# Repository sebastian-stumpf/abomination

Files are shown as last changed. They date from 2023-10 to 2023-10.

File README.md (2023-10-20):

# abomination

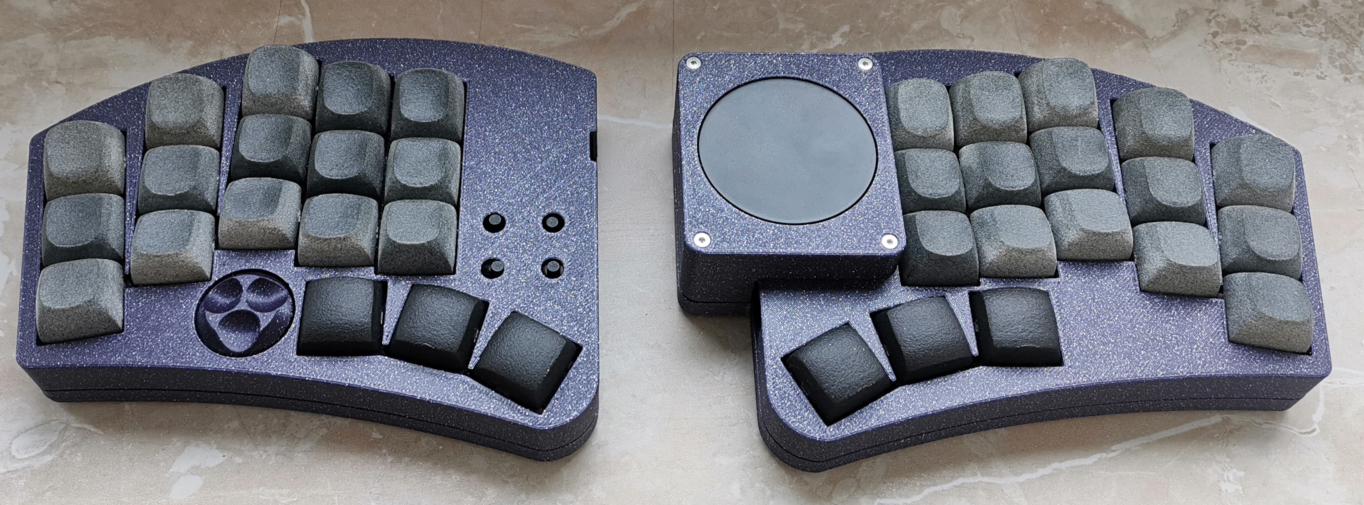
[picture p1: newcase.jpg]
abomination


## Attention

I'm a hobbyist/amateur at best. So there may be things that aren't optimized. That being said I've had the files
in the `gerbers/` directory manufactured at JLC with 1.6mm thickness and they work just fine with my fork of the qmk repository
directory. So if you decide to use this, then please be advised that I'm not providing any sort of liability and you should
exercise some caution.

## Trackpad

The trackpad relies on the following adapter https://github.com/keyboard-magpie/minimal-fpc-i2c-pcb/ which can cheapily be PCBA'ed.
There reasons for using this adapter are that I hate soldering those tiny clamshell connectors and I can easily hot swap the
trackpad with an OLED display.

## Case

There are two plate versions for the case. The default version is very thin and wobbly and the switches aren't pressed in easily.
There's also a 'thick' version of the plates that sits on the pcb rock solid and the switches pop in with ease. I'd heavily recommend
the thick version. Just be aware that it will consume about 4 times the material as the thin plate.

## BOM

| Quantity | Item | Comment |
| ---  | --- | --- |
| 2 | Helios or Liatris Controller | |
| 2 | IC-Sockets for MCU | Optional but recommended |
| 2 | TRRS Sockets | |
| 40 | 1N4148 SOD123 diodes | |
| 2 | SKHLLBA010 buttons | |
| 36 | MX Hotswap Sockets | |
| 1 | EC12 Encoders | |
| 4 | 6mm tactile switches | Longer caps work best |
| 36 | MX Switches + Keycaps | |
| 1 | Cirque 40mm curved trackpad | Desolder R1 for i2c |
| 1 | i2c adapter PCB for trackpad | see above |
| 1 | fpc cable for adapter | |
| 1 | 4 pin dip socket and header | for the adapter |
| a lot | M2 Screws (flat & countersunk) | |
| also a lot | M2 heat inserts | |
| 12 | round bumpons with 3,1mm dia | |

## Firmware

See [my fork](https://github.com/sebastian-stumpf/qmk_firmware/tree/sepp/keyboards/abomination) of the qmk repository. Nothing special here.
You can just copy the code over to your own repository and adjust the keymap.

## Feedback

I'm always happy to hear your opinions about this and if you decide to build this board then please do send me a picture of it.

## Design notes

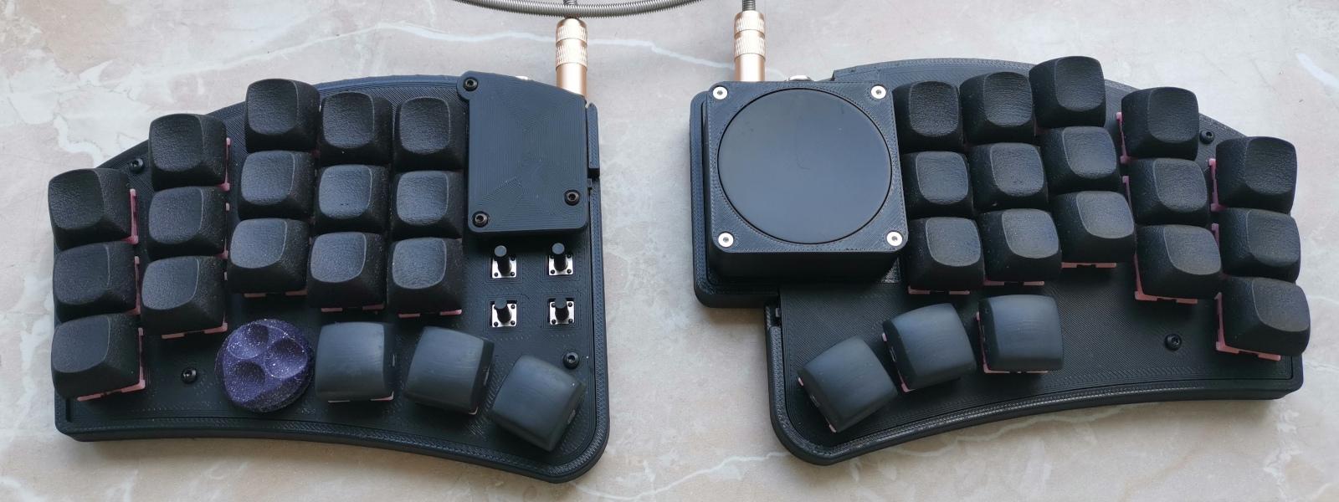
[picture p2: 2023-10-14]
abomination.jpg

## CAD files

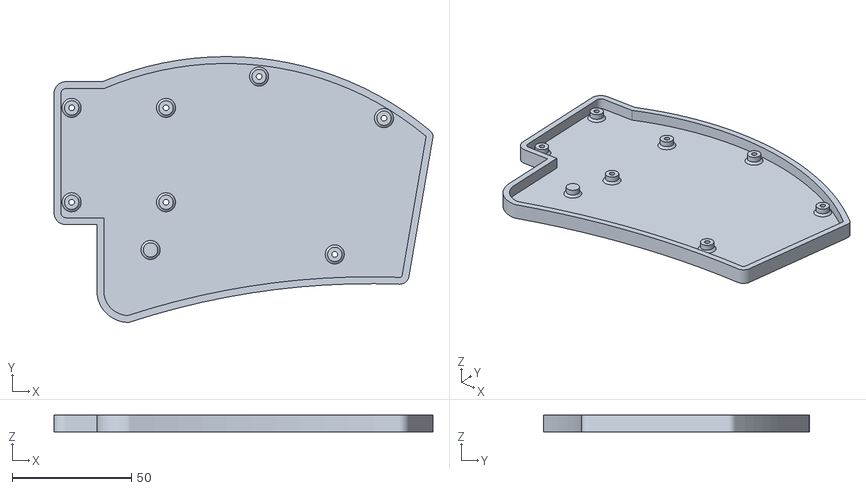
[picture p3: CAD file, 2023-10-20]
mechanical/case-new-right-bottom.stl
159.0 x 111.5 x 7.00

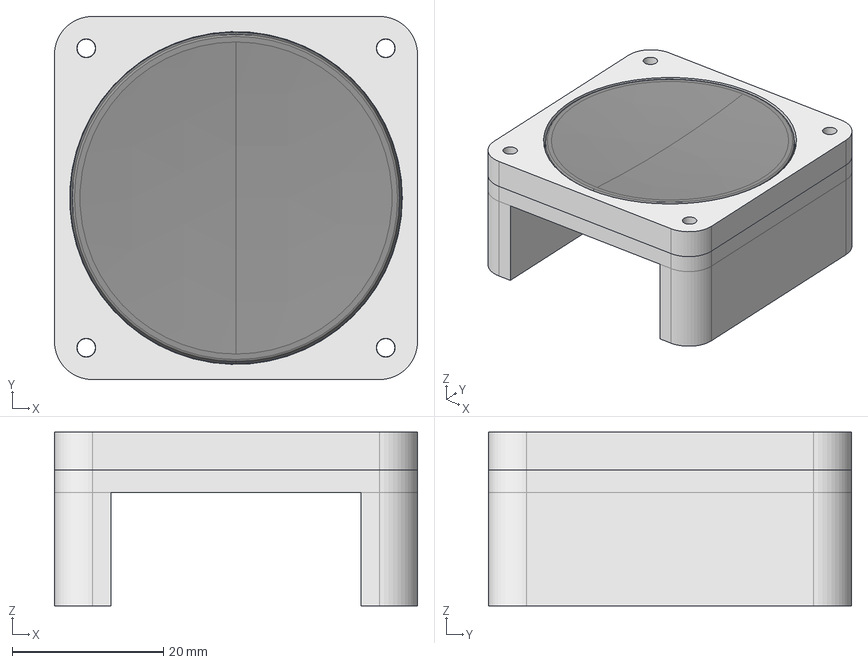
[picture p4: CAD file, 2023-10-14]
models/trackpad-holder.step
48.0 x 48.0 x 23.0 mm
trackpad
top
bottom

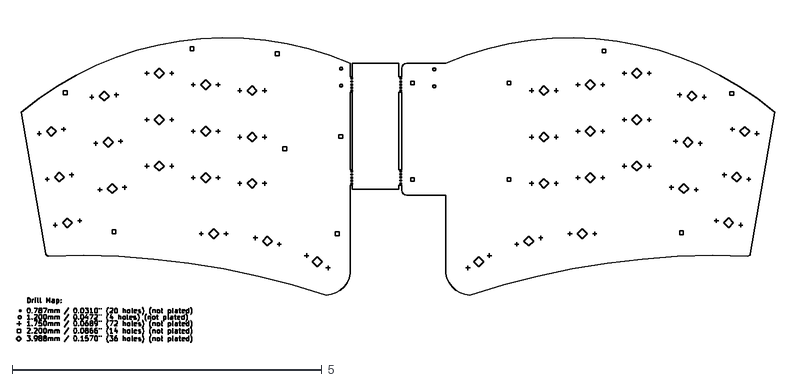
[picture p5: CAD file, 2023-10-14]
pcb/gerbers/abomination-NPTH-drl_map.dxf
12.2 x 5.27

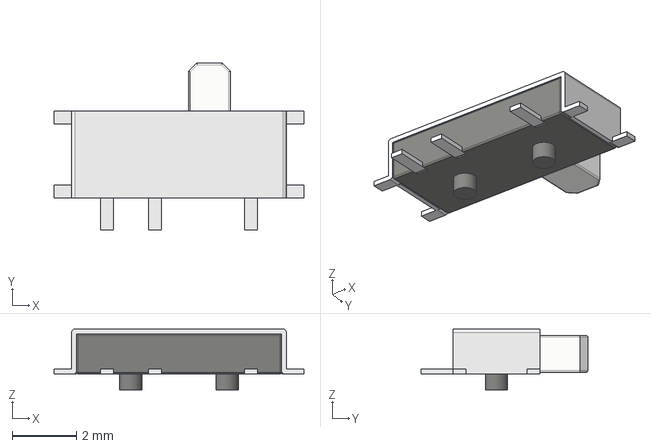
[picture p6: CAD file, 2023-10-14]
pcb/sepp/models/MSK12C02.step
7.80 x 5.20 x 1.90 mm

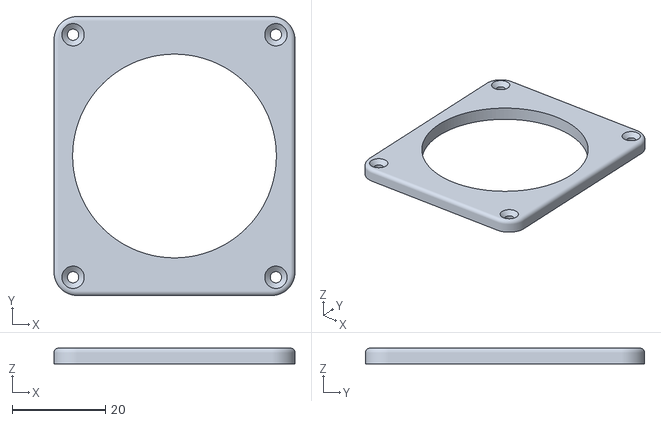
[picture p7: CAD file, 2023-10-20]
mechanical/case-new-right-cover.stl
51.8 x 60.0 x 3.41

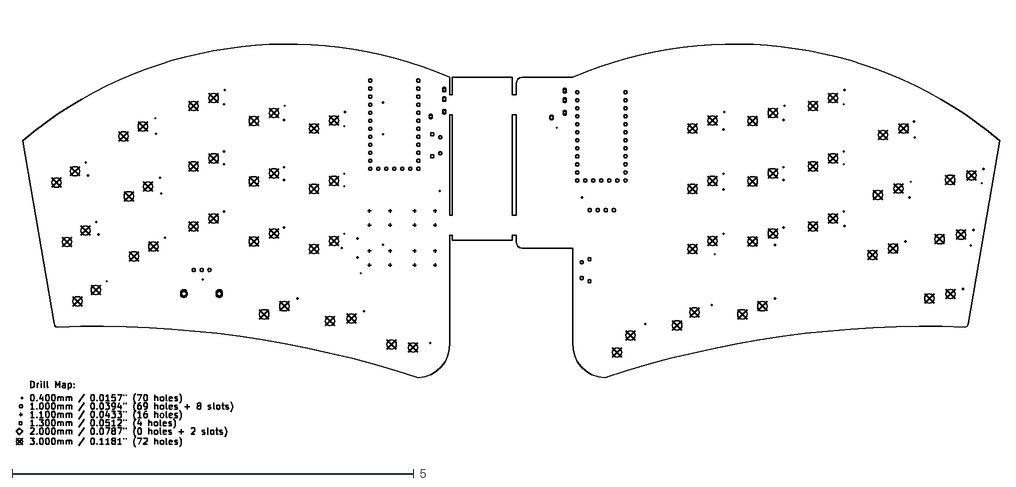
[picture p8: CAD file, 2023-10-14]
pcb/gerbers/abomination-PTH-drl_map.dxf
12.2 x 5.36

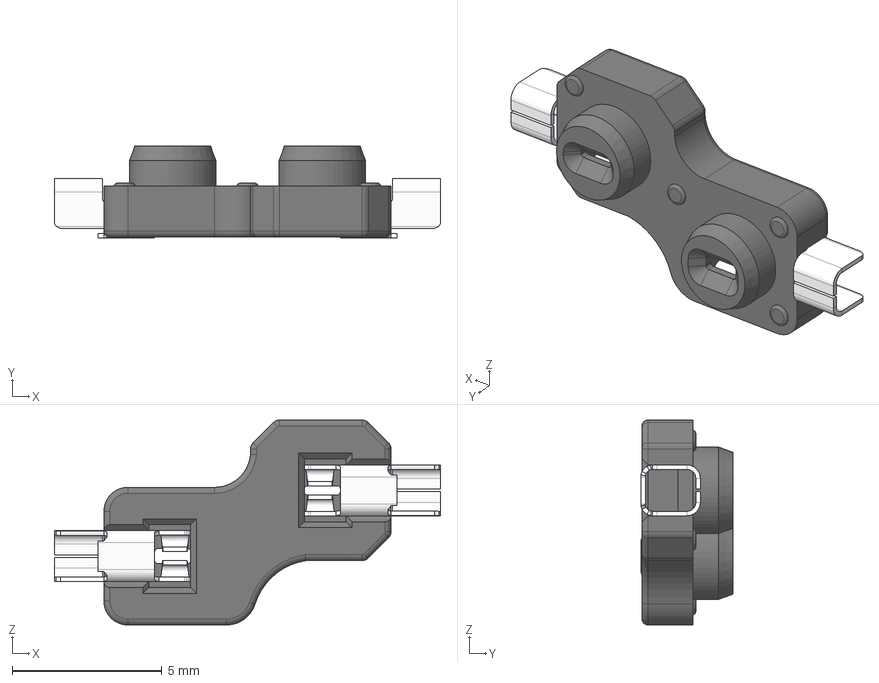
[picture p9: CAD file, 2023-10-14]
pcb/sepp/models/HS_Kailh_Choc.step
12.9 x 3.09 x 6.85 mm
pin x 2
socket

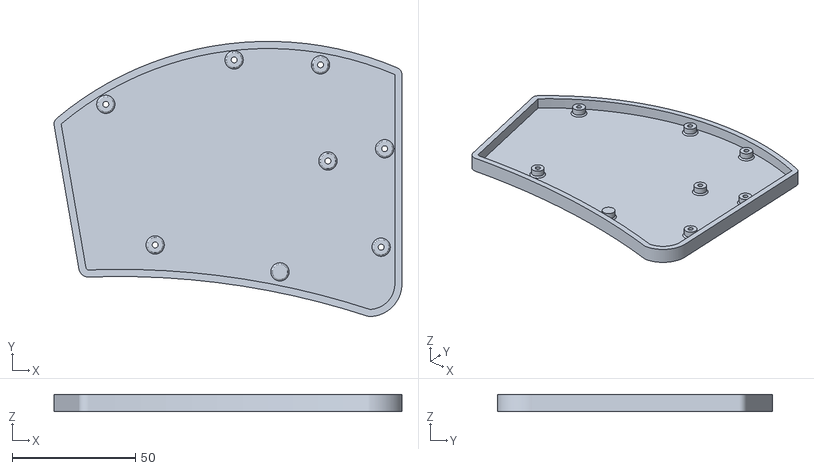
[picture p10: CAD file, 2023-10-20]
mechanical/case-new-left-bottom.stl
141.0 x 111.5 x 7.00

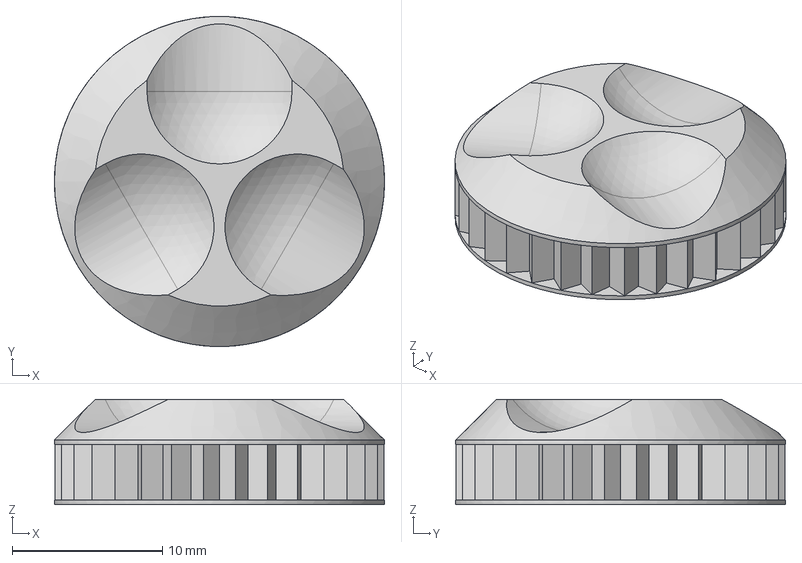
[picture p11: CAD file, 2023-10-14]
pcb/sepp/models/GEIST_EC12knob_v02_06.step
22.0 x 22.0 x 7.00 mm

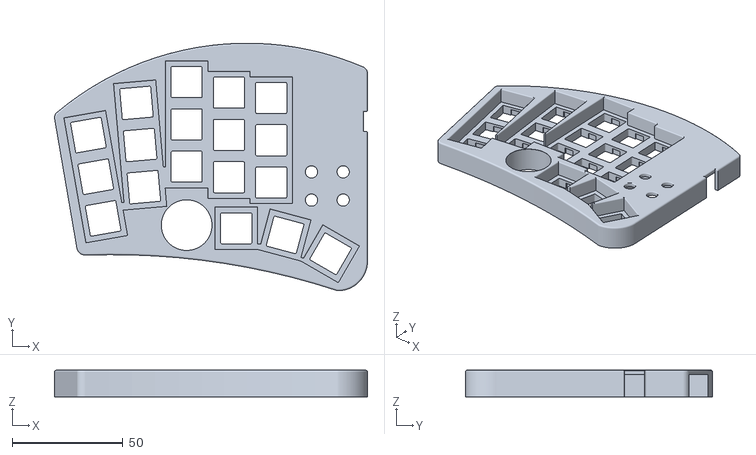
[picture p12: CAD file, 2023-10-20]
mechanical/case-new-left-top.stl
141.0 x 111.5 x 12.0

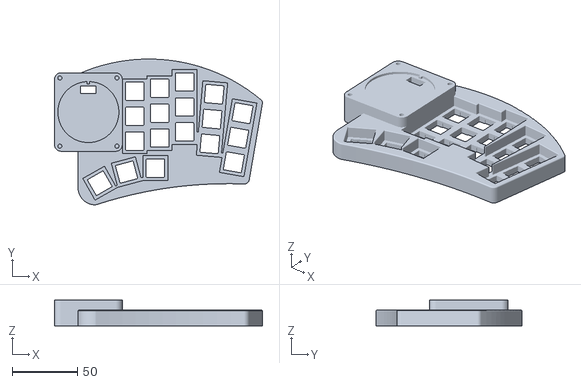
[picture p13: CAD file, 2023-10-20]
mechanical/case-new-right-top.stl
159.0 x 111.5 x 19.5

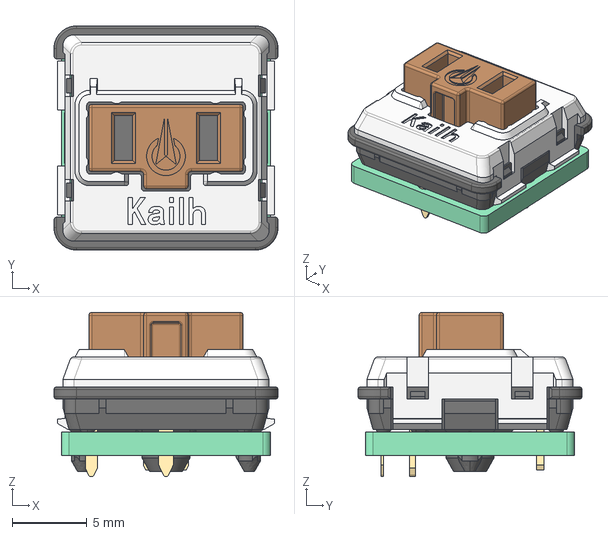
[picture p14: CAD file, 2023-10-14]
pcb/sepp/models/pg1350.step
15.0 x 15.0 x 11.0 mm

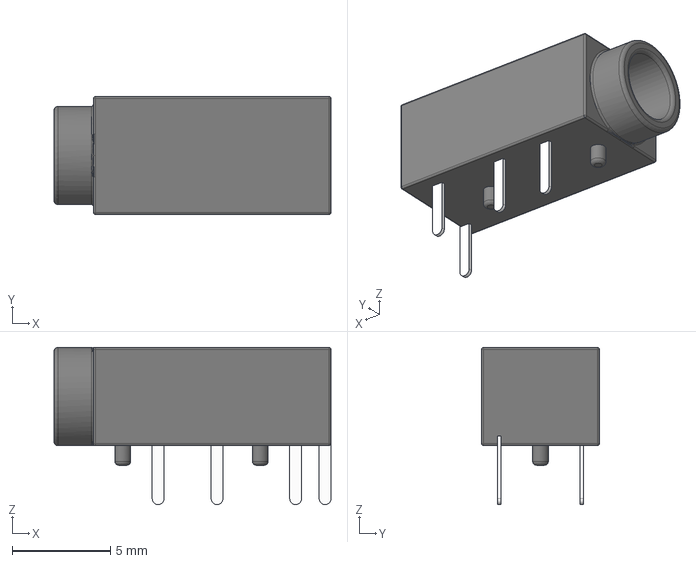
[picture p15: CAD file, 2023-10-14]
pcb/sepp/models/CON_MJ-4PP-9.step
14.1 x 6.00 x 8.00 mm

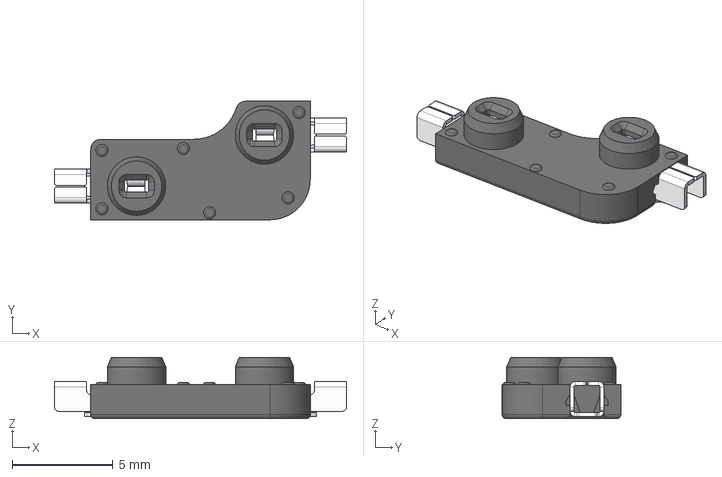
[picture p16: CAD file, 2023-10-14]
pcb/sepp/models/HS_Kailh_MX.step
14.5 x 5.89 x 3.05 mm
Contact x 2

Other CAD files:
pcb/sepp/models/SW_MSK12C02.step
pcb/sepp/models/xiao_rp2040.step
pcb/sepp/models/Liatris.step
pcb/sepp/models/MBK-1u.step
mechanical/old/case-left-bottom.stl
mechanical/old/case-left-cover.stl
mechanical/old/case-left-plate.stl
mechanical/old/case-left-thick-plate.stl
mechanical/old/case-right-bottom.stl
mechanical/old/case-right-plate.stl
mechanical/old/case-right-thick-plate.stl
mechanical/old/case-right-trackpad-plate.stl
mechanical/old/case-right-trackpad-top.stl
pcb/sepp/models/EC11-THT-15F-black.step
pcb/sepp/models/EC12E-085.step
pcb/sepp/models/LED_SK6812MINI-E.step
pcb/sepp/models/SKRTLAE010.step
pcb/sepp/models/SW_PUSH_6mm.step
pcb/sepp/models/SW_SKHLLC.step
pcb/sepp/models/abomination-trackpad-holder.step
pcb/sepp/models/cherry mx.STEP
pcb/sepp/models/fpc-connector-breakout.step
pcb/sepp/models/mx_kecap.step
pcb/sepp/models/pg1350-mbk.step

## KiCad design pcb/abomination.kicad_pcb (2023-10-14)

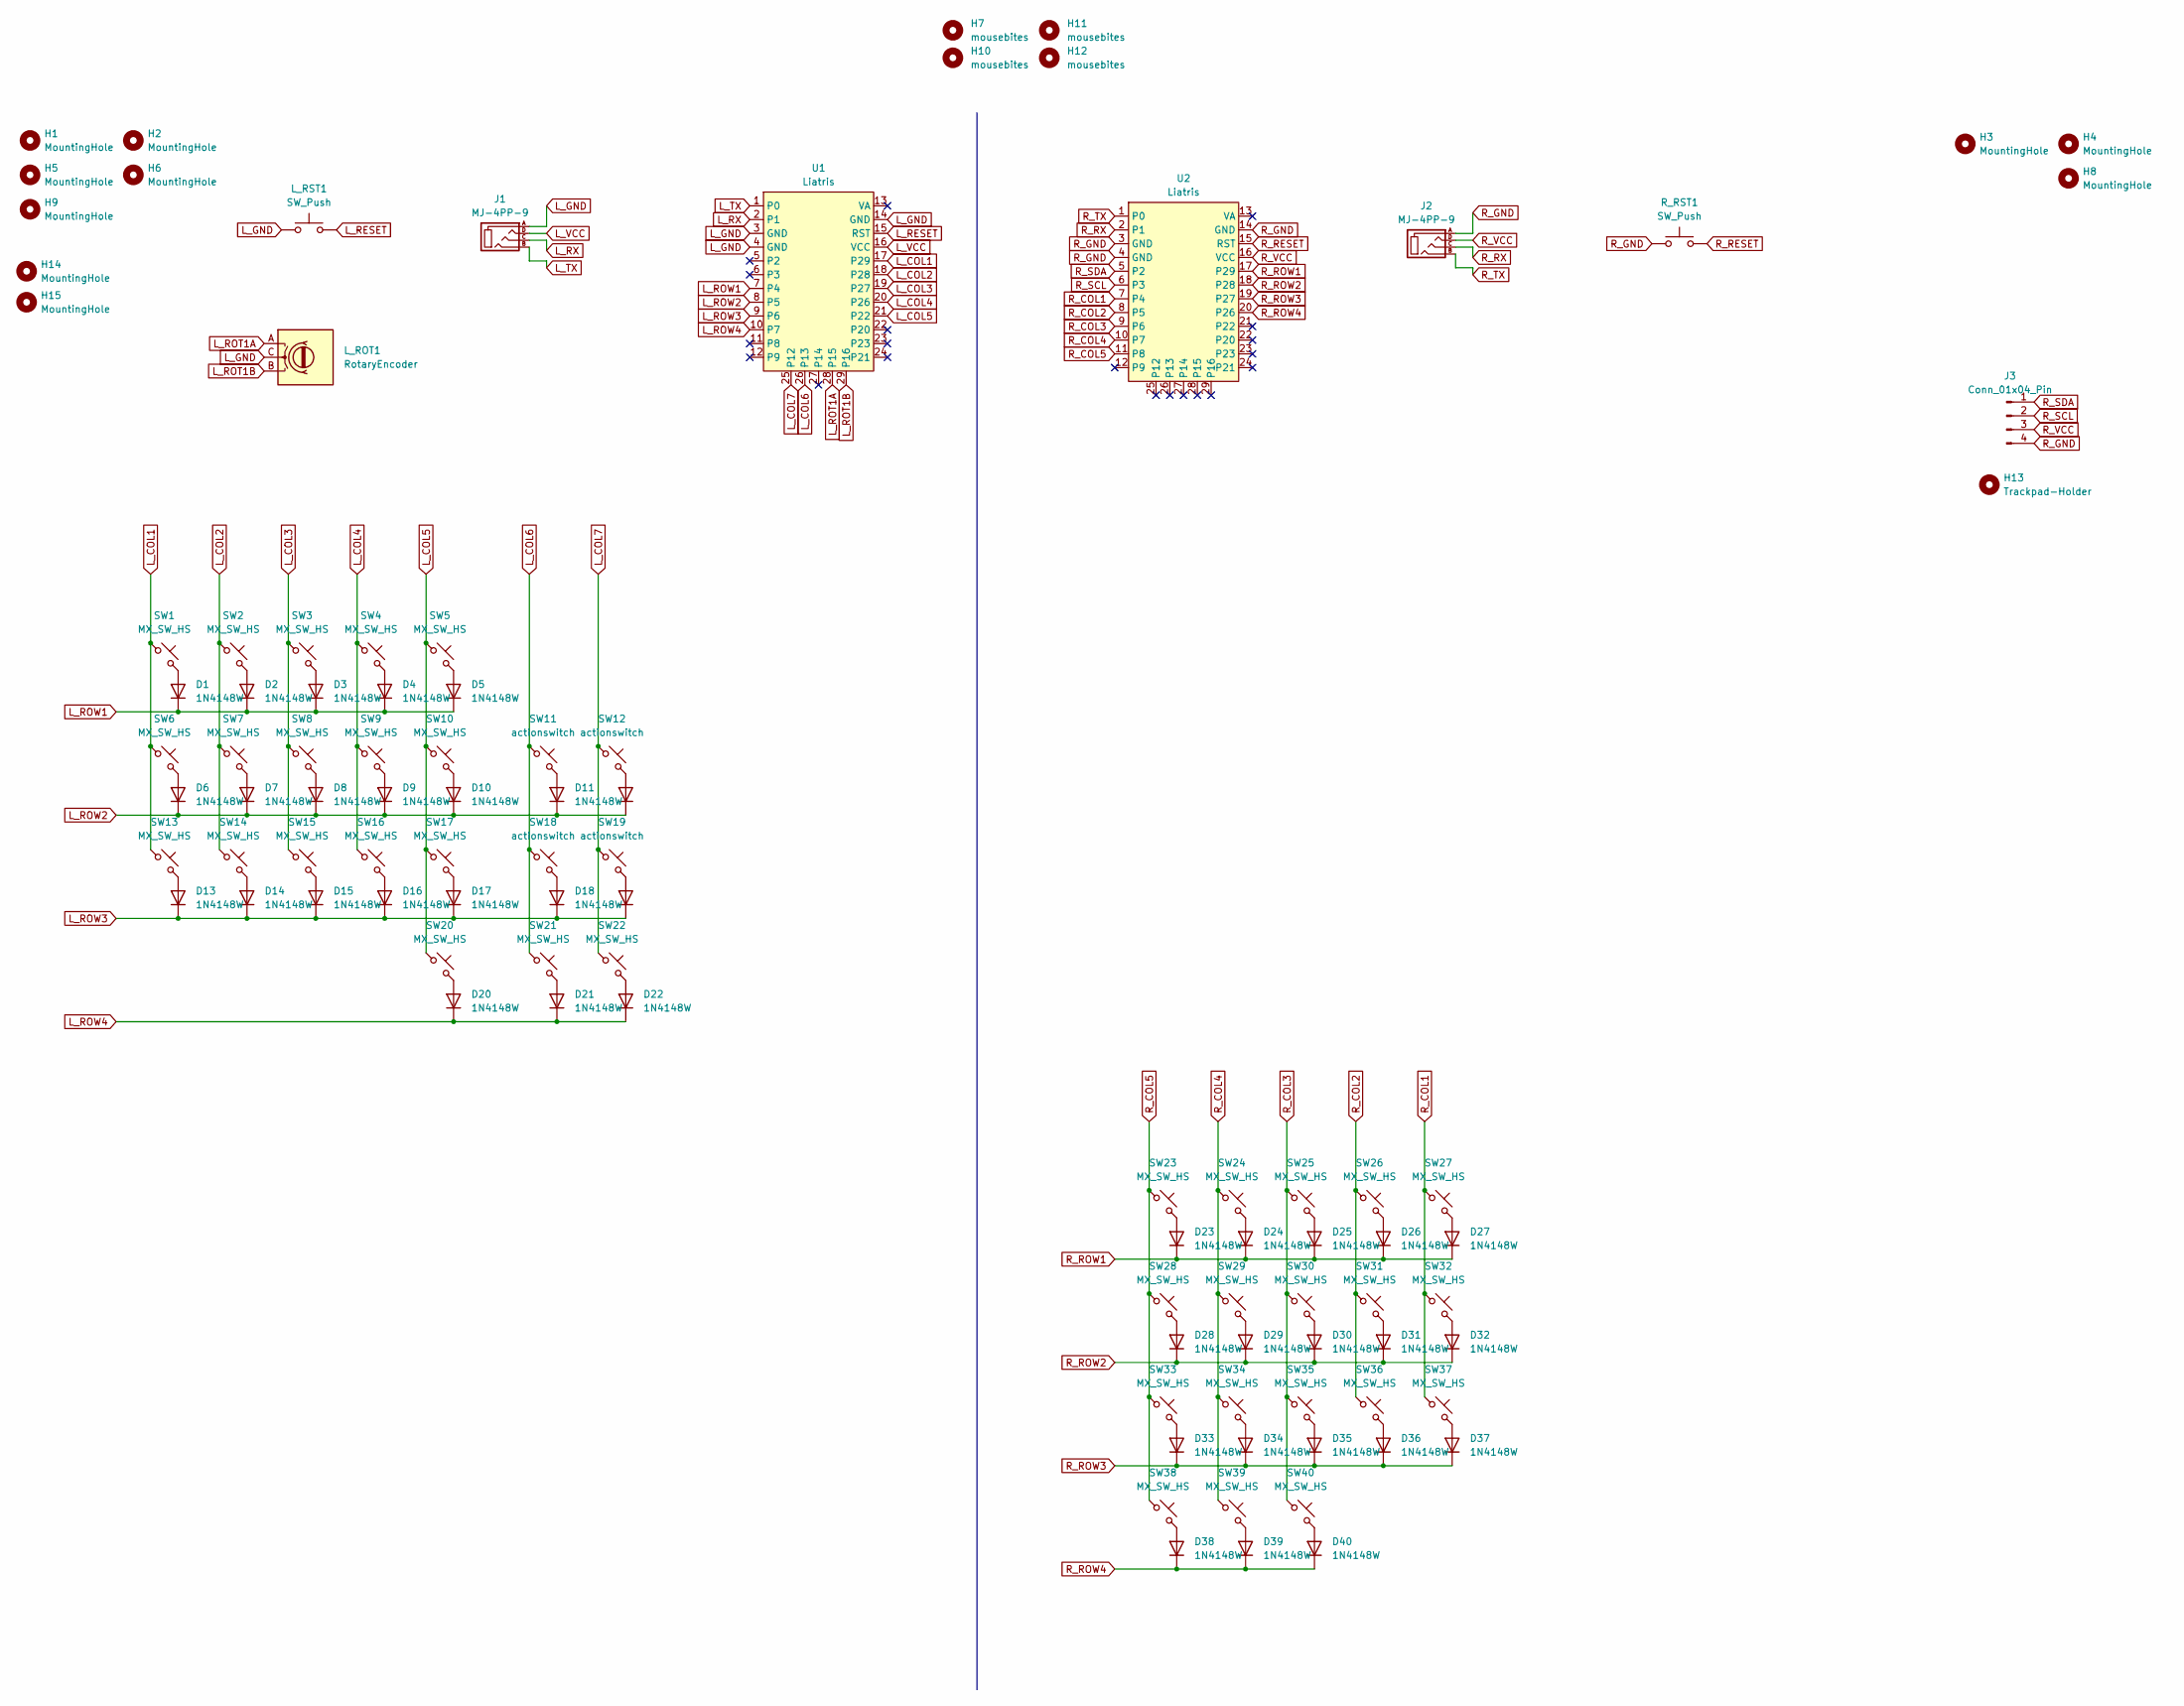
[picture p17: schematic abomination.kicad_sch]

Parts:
D1, D2, D3, D4, D5, D6, D7, D8, D9, D10, D11, D12, D13, D14, D15, D16, D17, D18, D19, D20, D21, D22, D23, D24, D25, D26, D27, D28, D29, D30, D31, D32, D33, D34, D35, D36, D37, D38, D39, D40: 1N4148W; D_SOD-123
H1, H2, H3, H4, H5, H6, H8, H9, H14, H15: MountingHole; MountingHole_2.2mm_M2_DIN965
H7, H10, H11, H12: mousebites; breakaway-mousebites
H13: Trackpad-Holder; abimination-trackpad-holder
J1, J2: MJ-4PP-9
J3: Conn_01x04_Pin; fpc-breakcout-connector
L_ROT1: RotaryEncoder; RotaryEncoder_Alps_EC12E_Vertical_H20mm
L_RST1: SW_Push; SW_SKHLLCA010
R_RST1: SW_Push; SW_SKHLLCA010
SW1, SW2, SW3, SW4, SW5, SW6, SW7, SW8, SW9, SW10, SW13, SW14, SW15, SW16, SW17, SW20, SW21, SW22, SW23, SW24, SW25, SW26, SW27, SW28, SW29, SW30, SW31, SW32, SW33, SW34, SW35, SW36, SW37, SW38, SW39, SW40: MX_SW_HS; SW_MX_HS_1u
SW11, SW12, SW18, SW19: actionswitch
U1, U2: Liatris; Liatris_AH_USBdn

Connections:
L_COL1: SW1.1, SW6.1, SW13.1, U1.17 (P29)
L_COL2: SW2.1, SW7.1, SW14.1, U1.18 (P28)
L_COL3: SW3.1, SW8.1, SW15.1, U1.19 (P27)
L_COL4: SW4.1, SW9.1, SW16.1, U1.20 (P26)
L_COL5: SW5.1, SW10.1, SW17.1, SW20.1, U1.21 (P22)
L_COL6: SW11.1, SW18.1, SW21.1, U1.26 (P13)
L_COL7: SW12.1, SW19.1, SW22.1, U1.25 (P12)
L_GND: J1.A, L_ROT1.C, L_RST1.1, U1.3 (GND), U1.4 (GND), U1.14 (GND)
L_RESET: L_RST1.2, U1.15 (RST)
L_ROT1A: L_ROT1.A, U1.28 (P15)
L_ROT1B: L_ROT1.B, U1.29 (P16)
L_ROW1: D1.1 (K), D2.1 (K), D3.1 (K), D4.1 (K), D5.1 (K), U1.7 (P4)
L_ROW2: D6.1 (K), D7.1 (K), D8.1 (K), D9.1 (K), D10.1 (K), D11.1 (K), D12.1 (K), U1.8 (P5)
L_ROW3: D13.1 (K), D14.1 (K), D15.1 (K), D16.1 (K), D17.1 (K), D18.1 (K), D19.1 (K), U1.9 (P6)
L_ROW4: D20.1 (K), D21.1 (K), D22.1 (K), U1.10 (P7)
L_RX: J1.C, U1.2 (P1)
L_TX: J1.B, U1.1 (P0)
L_VCC: J1.D, U1.16 (VCC)
unnamed: D1.2 (A), SW1.2
unnamed: D2.2 (A), SW2.2
unnamed: D3.2 (A), SW3.2
unnamed: D4.2 (A), SW4.2
unnamed: D5.2 (A), SW5.2
unnamed: D6.2 (A), SW6.2
unnamed: D7.2 (A), SW7.2
unnamed: D8.2 (A), SW8.2
unnamed: D9.2 (A), SW9.2
unnamed: D10.2 (A), SW10.2
unnamed: D11.2 (A), SW11.2
unnamed: D12.2 (A), SW12.2
unnamed: D13.2 (A), SW13.2
unnamed: D14.2 (A), SW14.2
unnamed: D15.2 (A), SW15.2
unnamed: D16.2 (A), SW16.2
unnamed: D17.2 (A), SW17.2
unnamed: D18.2 (A), SW18.2
unnamed: D19.2 (A), SW19.2
unnamed: D20.2 (A), SW20.2
unnamed: D21.2 (A), SW21.2
unnamed: D22.2 (A), SW22.2
unnamed: D23.2 (A), SW23.2
unnamed: D24.2 (A), SW24.2
unnamed: D25.2 (A), SW25.2
unnamed: D26.2 (A), SW26.2
unnamed: D27.2 (A), SW27.2
unnamed: D28.2 (A), SW28.2
unnamed: D29.2 (A), SW29.2
unnamed: D30.2 (A), SW30.2
unnamed: D31.2 (A), SW31.2
unnamed: D32.2 (A), SW32.2
unnamed: D33.2 (A), SW33.2
unnamed: D34.2 (A), SW34.2
unnamed: D35.2 (A), SW35.2
unnamed: D36.2 (A), SW36.2
unnamed: D37.2 (A), SW37.2
unnamed: D38.2 (A), SW38.2
unnamed: D39.2 (A), SW39.2
unnamed: D40.2 (A), SW40.2
R_COL1: SW27.1, SW32.1, SW37.1, U2.7 (P4)
R_COL2: SW26.1, SW31.1, SW36.1, U2.8 (P5)
R_COL3: SW25.1, SW30.1, SW35.1, SW40.1, U2.9 (P6)
R_COL4: SW24.1, SW29.1, SW34.1, SW39.1, U2.10 (P7)
R_COL5: SW23.1, SW28.1, SW33.1, SW38.1, U2.11 (P8)
R_GND: J2.A, J3.4, R_RST1.1, U2.3 (GND), U2.4 (GND), U2.14 (GND)
R_RESET: R_RST1.2, U2.15 (RST)
R_ROW1: D23.1 (K), D24.1 (K), D25.1 (K), D26.1 (K), D27.1 (K), U2.17 (P29)
R_ROW2: D28.1 (K), D29.1 (K), D30.1 (K), D31.1 (K), D32.1 (K), U2.18 (P28)
R_ROW3: D33.1 (K), D34.1 (K), D35.1 (K), D36.1 (K), D37.1 (K), U2.19 (P27)
R_ROW4: D38.1 (K), D39.1 (K), D40.1 (K), U2.20 (P26)
R_RX: J2.C, U2.2 (P1)
R_SCL: J3.2, U2.6 (P3)
R_SDA: J3.1, U2.5 (P2)
R_TX: J2.B, U2.1 (P0)
R_VCC: J2.D, J3.3, U2.16 (VCC)

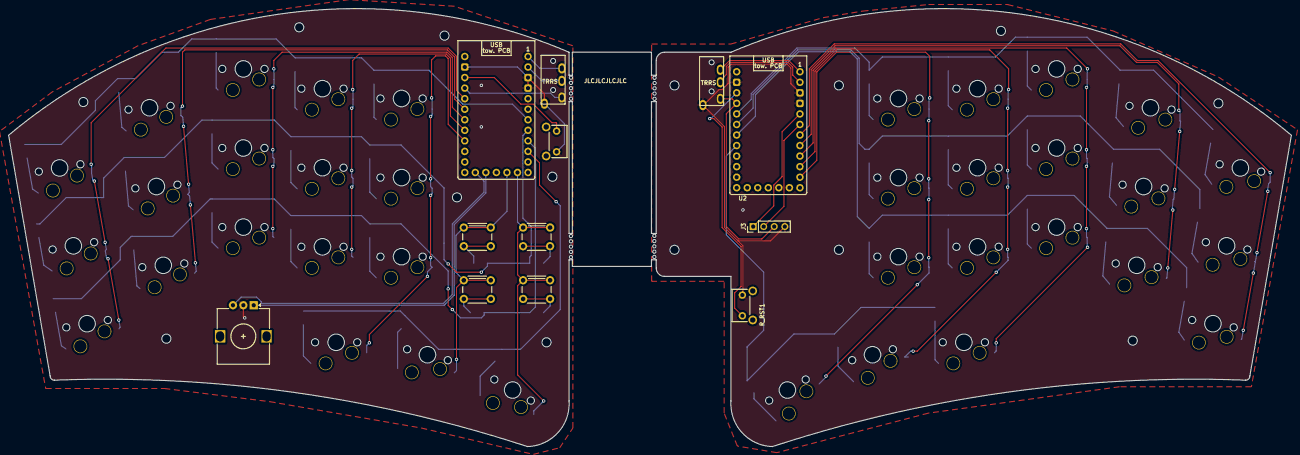
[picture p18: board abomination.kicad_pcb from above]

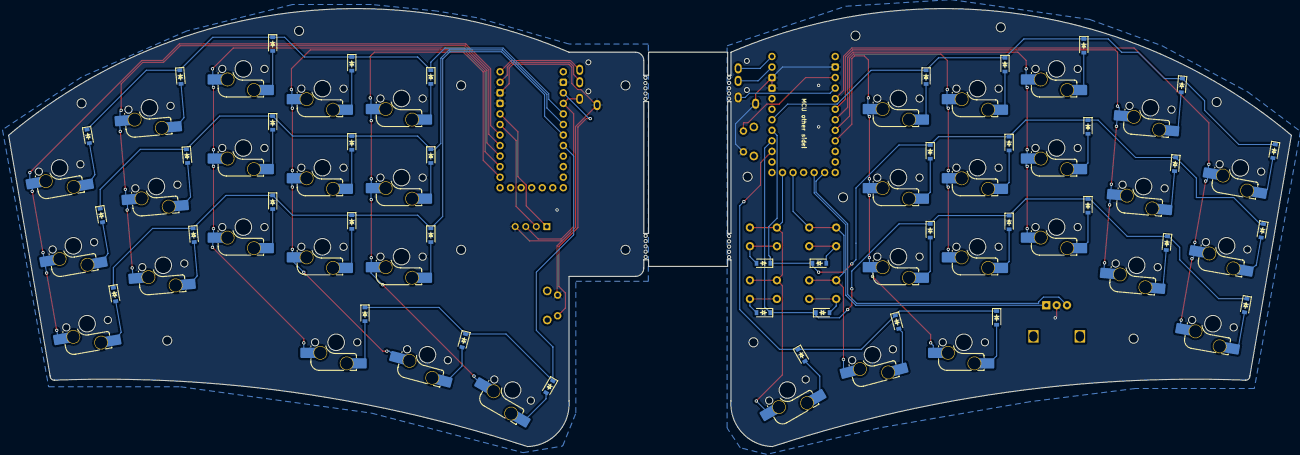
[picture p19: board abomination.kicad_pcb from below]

Board: 2 copper layers, 309.0 x 105.5 mm, 103 parts (40 on the bottom side), 74 nets.

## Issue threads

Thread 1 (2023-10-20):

Helios or Liatris Controller

sedghi, 2023-10-20:
Would it be possible to explain a little bit more about the differences or the pros or cons? Like which one is stronger?

sebastian-stumpf, 2023-10-25:
They share the same pinout, so at least for this board it doesn't make much difference. I prefer the Helios because it does have on board esd protection.
